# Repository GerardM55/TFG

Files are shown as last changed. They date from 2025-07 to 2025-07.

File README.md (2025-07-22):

# TFG
Este repositorio contiene todos los archivos relacionados con el proyecto de Trabajo de Fin de Grado titulado "Diseño y fabricación de un prototipo de prótesis de mano mioeléctrica con control de voz integrado".

La estructura del repositorio está organizada en las siguientes carpetas:

* Diseño mano

* PCB

* Pruebas

* Scripts finales

* Voz

Cada carpeta incluye los archivos correspondientes, así como un archivo README que explica el funcionamiento de los scripts y detalla los pasos necesarios para su instalación y ejecución.

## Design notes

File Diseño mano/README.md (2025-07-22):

La carpeta Diseño mano contiene los archivos necesarios para la impresión 3D del prototipo de prótesis de mano.
## Archivos SLDPRT 
Dentro de la subcarpeta Archivos SLDPRT se encuentran los archivos CAD en formato .SLDPRT, disponibles para su descarga y modificación.
Esta subcarpeta incluye tanto los archivos utilizados para la impresión del modelo final como versiones alternativas del diseño.
Los archivos .SLDPRT incluidos son los siguientes:
ajustadorSG90
* falange distal 1
* falange distal 2
* falange distal 3
* falange distal 4
* falange distal 5
* falange media 2
* falange media 3
* falange media 4
* falange media 5
* falange proximal 1
* falange proximal 2
* falange proximal 3
* falange proximal 4
* falange proximal 5
* Forearm
* LeftWristCableGuide
* mano
* ServoHolder
* ServoHornPulley
* MCF
* pasador
* soporteSG90
* falange proximal 2 sp
* falange proximal 3 sp
* falange proximal 4 sp
* falange proximal 5 sp 
* caja
* tapa
* ArmStand

## Archivos STL
La carpeta Archivos STL contiene los archivos en formato .STL, preparados y listos para la impresión 3D de las piezas del prototipo.
Los archivos .STL incluidos son los siguientes:
* ajustadorSG90
* falange distal 1
* falange distal 2
* falange distal 3
* falange distal 4
* falange distal 5
* falange media 2
* falange media 3
* falange media 4
* falange media 5
* falange proximal 1
* falange proximal 2
* falange proximal 3
* falange proximal 4
* falange proximal 5
* Forearm
* LeftWristCableGuide
* mano
* ServoHolder
* ServoHornPulley
* MCF
* pasador
* soporteSG90
* falange proximal 2 sp
* falange proximal 3 sp
* falange proximal 4 sp
* falange proximal 5 sp
* caja
* tapa
* ArmStand

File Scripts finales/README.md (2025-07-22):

# Descripción del directorio
En este directorio se encuentran todos los scripts necesarios para la ejecución del sistema. A continuación, 
se explican detalladamente. 

## apagado_script.sh 
El script **apagado_script.sh** es un script de shell que su función es registrar en un archivo de log con 
el inicio y final de su ejecución, junto con la ejecución del script **apagar_ads1292.py**. 
El archivo es ejecutado cuando el pulsador de la PiJuice Zero es presionado dos veces seguidas. 

## apagar_ads1292.py
El script tiene la función de apagar el sistema operativo, concretamente la alimentación a la Raspberry Pi Zero 2W
a través de la PiJuice. 

### Descripción

El script realiza las siguientes acciones:

* Inicializa la comunicación con el dispositivo PiJuice vía I2C.

* Registra en un archivo de log el inicio del proceso de apagado.

*Espera 2 segundos para asegurar el cierre limpio de conexiones.

* Envía la orden de corte de energía para que el PiJuice apague el sistema en 15 segundos.

* Registra en el log la confirmación de la orden enviada o cualquier error ocurrido.

### Requisitos
Las librerías de Python necesarias para la ejecución del script son: 
````
pip install pijuice
````
### Salida 
El script genera un archivo de log en _/home/raspberry/logs/apagar_ads1292.log_ donde se registran los eventos y posibles errores del proceso de apagado.

## inicio_script.sh
Este script de shell es el encargado de la inicialización del sistema. Esta tiene lugar al presionar una vez el pulsador de la Pijuice Zero. 

### Descripción
El archivo realiza las siguientes tareas: 

* Crea los directorios necesarios para logs y notificaciones.

* Finaliza cualquier proceso lgd previo y lanza uno nuevo con la ruta de notificación personalizada.

* Exporta la variable de entorno LGPIO_DIR para asegurar el funcionamiento correcto de lgpio.

* Activa el entorno virtual de Python.

* Carga el overlay de sonido para Google Voice HAT.

* Recarga ALSA para detectar dispositivos de audio.

* Ejecuta el script **script_principal.py** y lo redirige a un archivo de log.

### Requisitos
No se necesita ninguna librería en particular para ejecutar el archivo. 

### Salida 
Se generan dos archivos de log en /home/raspberry/logs:

* **servicio_arranque.log**: Registra los eventos generales del arranque del sistema y la ejecución del script.

* **script_principal.out**: Captura la salida del script Python principal **script_principal.py**, incluyendo posibles errores de ejecución.

## script_principal.py
Es el script encargado de controlar la ejecución principal del sistema y de llamar a los distintos scripts en función de las acciones a realizar. 

### Descripción
El script realiza las siguientes acciones:
* Inicialización de GPIO y recursos compartidos
* Lectura del modo actual
* Modo EMG:
    * Se activa la interfaz SPI del módulo ADS1292 para comenzar la adquisición de señales EMG.
    * Se capta la contracción muscular
    * Si la mano está abierta, se ejecuta el agarre "general".
    * Si la mano está cerrada, se ejecuta "stop".
* Modo voz:
    * Se llama a la función principal del módulo grabar_audio que graba el audio y devuelve una etiqueta con el agarre deseado
    * Si el agarre previo era "stop", se ejecuta el agarre deseado.
    * Si el agarre previo era diferente a "stop", se ejecuta el agarre "stop".
    * El sistema espera 3 segundos por si el usuario quiero cambiar de modo.

### Requisitos
Las librerías necesarias para la ejecución del script son:
````
pip install lgpio
pip install flask
pip install pydub
pip install joblib
pip install vosk
````
### Salida
El script muestra a través de prints el estado de la ejecución. 

## grabar_audio.py
Este script es el encargado de la grabación y transcripción del audio. A continuación, se detalla su funcionamiento. 

### Descripción
El script realiza las siguientes acciones:
* Configuración de GPIO e interrupciones
* Grabación del audio a través de I2S con ALSA.
* El audio se guarda en un archivo wav
* Conversión y transcripción del audio con el transcriptor Vosk
* Limpieza y clasificación del agarre.
* Se devuelve la etiqueta del agarre al script principal.
* Se cierra el I2S y se liberan las GPIOs correspondientes.

### Requisitos
Las librerías necesarias para la ejecución del script son:
````
pip install lgpio
pip install alsaaudio
pip install pydub
pip install joblib
pip install vosk
pip install scikit-learn
pip install unicodedata
````
### Salida
La salida de este script es la devolución del resultado de la transcripción del audio a través de la variable **etiqueta** en la función **main()**. 

## PCA9685.py 
Este script es el encargado de establecer conexión con el módulo PCA9685 y gestionar el movimiento de los servomotores en función del agarre seleccionado. 

### Descripción
El script realiza las siguientes acciones:
* Configura el bus I2C
* Según el tipo de agarre solicitado, determina qué dedos mover, en qué dirección y con qué tipo de movimiento:
  * **R**: Movimiento sin realimentación.
  * **S**: Movimento con realimentación.
* Configura el MUX para gestionar la realimentación en caso de que el agarre no sea ni "stop" ni "general".
* Mueve cada servo al valor definido en el agarre.
* Finaliza liberando recursos (I2C, GPIOs).

### Requisitos
Las librerías necesarias para la ejecución del script son:
````
pip install adafruit-circuitpython-pca9685 lgpio
````

### Salida
El script muestra su estado a través de prints. La salida es visual con los movimientos de los servomotores. 

## ADS1292.py
Este script es el encargado de controlar el ADS1292, el cual tiene dos funciones principales:
* Lectura de la señal EMG.
* Lectura de la realimentación de los servomotores.

### Descripción 
A continuación, se detalla el proceso de ejecución en función del modo utilizado
* Inicializa el bus SPI
* Configura los registros del ADS1292 en función del modo.
* Modo EMG:
    * Espera 6 segundos.
    * Realiza la adquisición de picos para establecer unos margenes para la calibración de picos.
    * Realiza la calibración de picos para establecer un threshold para la detección de la contracción muscular.
    * Adquiere muestras hasta detectar una contracción muscular.
* Modo voz:
    * Calcula el valor de la corriente del servomotor.
    * Devuelve si el servomotor ha superado el límite de corriente.
* Finaliza el bus SPI y libera las GPIOS correspondientes 

### Requisitos
Las librerías necesarias para la ejecución del script son:
````
pip install lgpio numpy scipy
````
### Salida
El script muestra a través de prints los valores adquiridos con el ADS1292.

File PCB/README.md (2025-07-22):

Este directorio contiene dos archivos comprimidos en formato .zip, correspondientes a las placas PCB diseñadas para el proyecto.
Cada archivo .zip incluye dos archivos en formato .json:
PCB.json: Diseño de la placa de circuito impreso (PCB).
schematic.json: Esquema eléctrico con todos los componentes utilizados.

## PCB_1.zip
Contiene el primer modelo de PCB desarrollado durante el proyecto. Este diseño resultó no ser funcional y fue descartado en etapas posteriores.

## PCB_definitiva.zip
Contiene el diseño final de la PCB, utilizado en el modelo funcional del prototipo.

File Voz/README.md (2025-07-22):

Este directorio contiene todos los scripts relacionados con el procesamiento y clasificación de comandos de voz. 
Los archivos están organizados en tres subcarpetas, en función del tipo de preprocesamiento aplicado.
## Algoritmo clasificador
Esta carpeta incluye todos los algoritmos clasificadores entrenados para ser el algoritmo clasificador final. 
Se incluyen 3 subcarpetas divididas en función del algoritmo de preprocesamiento utilizado. Estas 3 carpetas son: 
### MFCC
Este directorio contiene los algoritmos clasificadores entrenados con el preprocesamiento mediane MFCC (Mel-Frequency Cepstral Coefficients ). 
Los algoritmos clasificadores utilizados son el **MLPClassifier, el Random Forest y el SVM**. 
La estructura y funcionamiento de los 3 códigos implementados es la siguiente:
##### Descripción
El programa realiza las siguientes tareas:

* Carga y procesamiento de audios en formato .wav, aplicando:

* Reducción de ruido

* Normalización

* Extracción de características MFCC + deltas

* Clasificación de comandos mediante el algoritmo clasificador seleccionado optimizado con GridSearchCV.

* Evaluación del modelo usando métricas de precisión y matriz de confusión.

* Exportación del modelo entrenado en formato .pkl.

##### Estructura de carpetas esperada
Los audios deben estar organizados por carpetas, una por tipo de agarre o comando. Ejemplo:
```
audio_agarre_normalizados/
├── agarre_cilindrico/
├── agarre_gancho/
├── agarre_obliquo/
├── agarre_pinza/
├── agarre_pinza_lateral/
├── otro/
└── stop/

```
##### Requisitos
Instala las dependencias necesarias con:

```
pip install -r requirements.txt
```
(El archivo requirements.txt debe incluir: librosa, noisereduce, pydub, scikit-learn, matplotlib, joblib, psutil, etc.)

#### Salida
* Precisión del modelo y visualización de la matriz de confusión

* Mejores hiperparámetros encontrados

### Vosk
El directorio siguiente contiene los scripts utilizados para entrenar los algoritmos clasificadores aplicando el transcriptor Vosk. 
Estos algoritmos son: **Linear Regression, MLPClassifier, Random Forest, SVM y XGBoost**. 
La estructura y funcionamiento de los códigos implementados es la siguiente:
#### Descripción
El sistema sigue los siguientes pasos:
* Carga y preprocesamiento de audios

* Normalización de volumen

* Reducción de ruido de fondo

* Transcripción automática usando el modelo de Vosk en español para convertir voz en texto

* Limpieza del texto transcrito mediante la lliminación de acentos y caracteres especiales

* Vectorización del texto

* Entrenamiento del modelo con el algoritmo clasificador seleccionado. 

* Optimización de hiperparámetros con GridSearchCV

* Evaluación del rendimiento
#### Estructura de las carpetas
Los audios están organizados por etiquetas en las siguientes rutas (modificables en el script):
````
Control_de_veu/
├── audio_agarre_normalizados/
│   ├── agarre_cilindrico/
│   ├── agarre_gancho/
│   ├── agarre_obliquo/
│   ├── agarre_pinza/
│   ├── agarre_pinza_lateral/
│   ├── otro/
│   └── stop/
├── vosk-model-es-0.42/
````
#### Requisitos
Asegúrate de tener instaladas las siguientes librerías de Python:
````
pip install numpy pydub noisereduce vosk scikit-learn matplotlib joblib
````
#### Salida
* Precisión impresa en consola.

* Matriz de confusión mostrada con matplotlib.

### Whisper
En esta carpeta se encuentra un modelo con el algoritmo clasificador **MLPCLassifier** y el transcriptor **Whisper ai**. 
La estructura y funcionamiento del códigos es la siguiente:
#### Descripción
El flujo del sistema es el siguiente:

* Carga y preprocesamiento de audios

* Transcripción con el modelo Whisper small en español.

* Limpieza y clasificación semántica

* Extracción de características semánticas

* Clasificación con el modelo MLPClassifier que se entrena con las transcripciones vectorizadas.

* Evaluación mediante el accuracy y una matriz de confusión.

#### Estructura de las carpetas
La estructura de las carpetas es la siguiente: 
````
Control_de_veu/
└── audio_agarre_normalizados/
    ├── agarre_cilindrico/
    ├── agarre_gancho/
    ├── agarre_obliquo/
    ├── agarre_pinza/
    ├── agarre_pinza_lateral/
    ├── stop/
    └── otro/
````
#### Requisitos
Las líbrerias necesarias son las siguientes: 
````
pip install openai-whisper pydub rapidfuzz sentence-transformers scikit-learn matplotlib joblib
````
#### Salida
* Se calcula la precisión del modelo sobre el conjunto de prueba.

* Se muestra una matriz de confusión con los resultados por palabra.

## Detección de voz
En este directorio se encuentran los scripts **deteccion_hyperparametros.py** y **deteccion_voz.py** encargados de la detección de voz del usuario. 
Estos scripts no han sido aplicados al modelo final. A continuación, se detalla los requisitos y estructura de los códigos. 
### deteccion_hyperparametros
Este script implementa un sistema de detección de voz que distingue entre la voz del usuario y la de otras personas. 
Para ello, utiliza un preprocesamiento con MFCC y una red neuronal X-Vector entrenada con PyTorch.

#### Descripción
El sistema realiza las siguientes acciones:
* Carga y preprocesamiento de datos de audio

* Extracción de características (MFCC) con data augmentation

* Definición de un Dataset personalizado

* Entrenamiento de una red neuronal X-Vector

* Búsqueda de hiperparámetros

* Evaluación del rendimiento

* Verificación de hablante a partir de un archivo .wav

#### Estructura de las carpetas
La estructura de las carpetas es la siguiente: 
````
Control_de_veu/
├── audios_deteccio_veu/
│   ├── meva_veu_aug_2/         # Audios de entrenamiento - mi voz
│   ├── altres_veu_aug_2/       # Audios de entrenamiento - otras voces
│   ├── meva_veu_test/          # Audios de test - mi voz
│   └── altres_veu_test/        # Audios de test - otras voces
````
#### Requisitos
Las líbrerias necesarias para ejecutar este script son: 
````
pip install torch librosa numpy scikit-learn
````
#### Salida
* Precisión del modelo. 

* Mejores hiperparámetros encontrados

### deteccion_voz
Este script es una replica del script anterior pero utilizando los mejores hiperparámetros extraidos del código anterior. 
Por lo tanto, la estructura y los requisitos del código son los mismos que el anterior script. 

## Preprocesamiento
En este directorio se encuentran los scripts utilizados para el preprocesamiento de los audios. 
Estos basicamente se dividen en los scripts de data augmentation de la detección de voz, donde se encuentran 
el script **DA_deteccion_mi_voz.py** y **DA_deteccion_otra_voz.py**. Como el nombre del archivo indica,
uno es para el DA de los audios de la voz del usuario y el otro para el DA de los audios externos. 
Posteriormente, hay el script **data_augmentation_audios.py** encargado del DA de los audios de los agarres 
y finalmente, el script **normalizacion_audio.py**, que es el script referente a la normalización de los audios a 16 KHz. 

### DA_deteccion_mi_voz.py, DA_deteccion_otra_voz.py y data_augmentation_audios.py
Estos tres scripts son los encargados del DA. La diferencia entre ellos radica en las carpetas asociadas.

#### Descripción
Los scripts realizan el siguiente: 
* Cargar audios `.wav` desde la carpeta de origen
* Aplicar **data augmentation**
* Guardar tanto el audio original como las versiones aumentadas en la carpeta de destino
  
#### Técnicas aplicadas
* **PitchShift**: Cambia el tono del audio
* **TimeStretch**: Acelera o ralentiza ligeramente el audio
* **AddGaussianNoise**: Añade ruido gaussiano al audio
* **Gain**: Ajusta el volumen general

#### Estructura de las carpetas
La estructua de las carpetas para el script **DA_deteccion_mi_voz.py** es la siguiente: 
````
Control_de_veu/
│
├── audios_deteccio_veu/
│   ├── meva_veu_aug/
│   ├── meva_veu_aug_2/
````
Para el script **DA_deteccion_otra_voz.py**: 
````
Control_de_veu/
│
├── audios_deteccio_veu/
│   ├── altres_veu_aug/
│   ├── altres_veu_aug_2/
````
Y para el script **data_augmentation_audios.py**: 
````
Control_de_veu/
│
└── audio_agarre/
    ├── agarre_X/
    └── agarre_X_aug/
````
#### Requisitos
Las líbrerias necesarias son: 
````
pip install librosa audiomentations numpy soundfile
````
#### Salida
La salida de los scripts es el audio original junto con los audios generados aplicando DA. 

### normalizacion_audio.py
Este script normaliza los audios de entrada a una frecuencia de 16 KHz.
#### Descripción
* Recorre de forma recursiva una carpeta de entrada con archivos .wav

* Convierte los audios que no estén a 16 kHz

* Guarda los audios normalizados en una carpeta de salida

#### Estructura de las carpetas
La estructura de las carpetas es la siguiente. 
````
Control_de_veu/
│
└── audio_agarre/
    ├── agarre_X/
    └── agarre_X_aug/
````
#### Requisitos
Las líbrerias necesarias son: 
````
pip install librosa soundfile
````
#### Salida
La salida del script son los audios normalizados a 16 KHz.

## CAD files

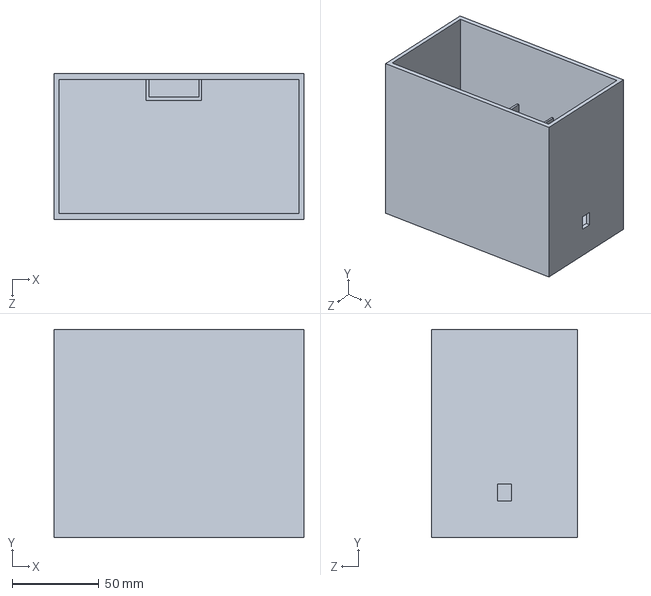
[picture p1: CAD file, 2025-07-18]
Diseño mano/Archivos SLDPRT/caja.SLDPRT
144.0 x 120.0 x 84.0 mm

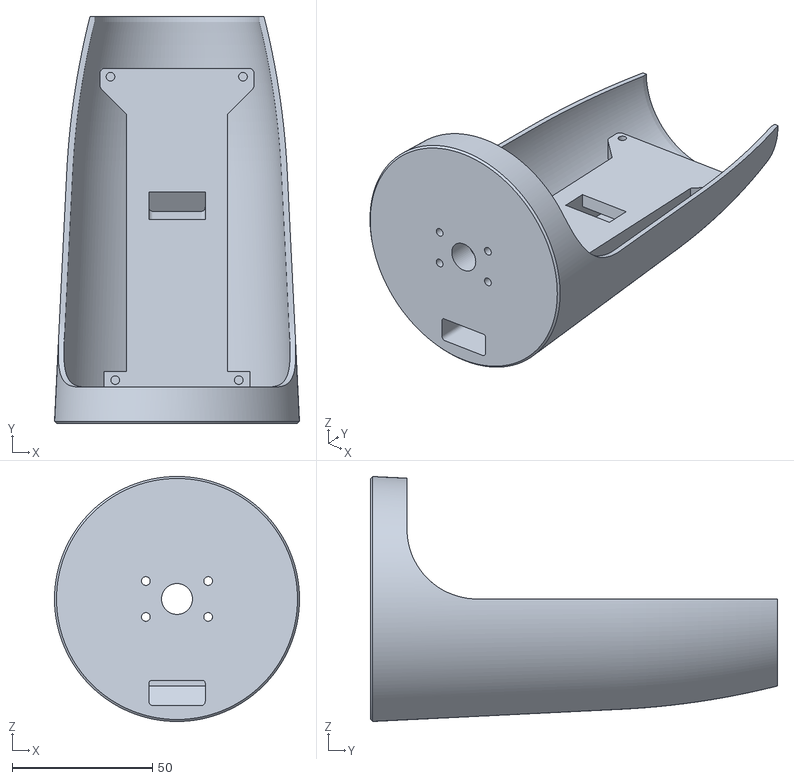
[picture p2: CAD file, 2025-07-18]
Diseño mano/Archivos STL/Forearm.stl
87.3 x 145.0 x 87.3

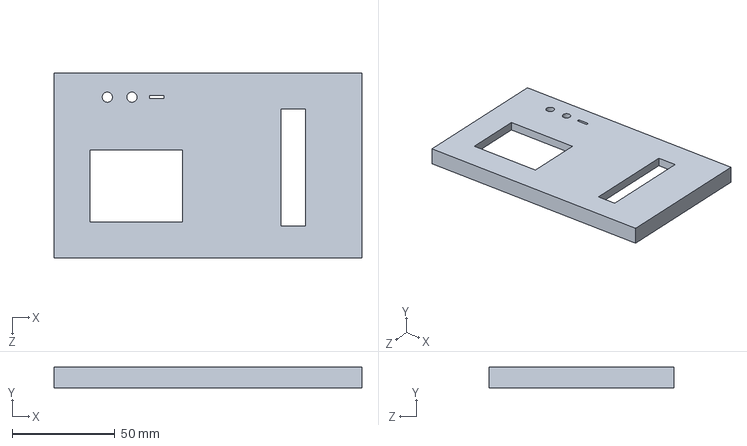
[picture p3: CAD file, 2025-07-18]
Diseño mano/Archivos SLDPRT/tapa.SLDPRT
150.0 x 10.0 x 90.0 mm

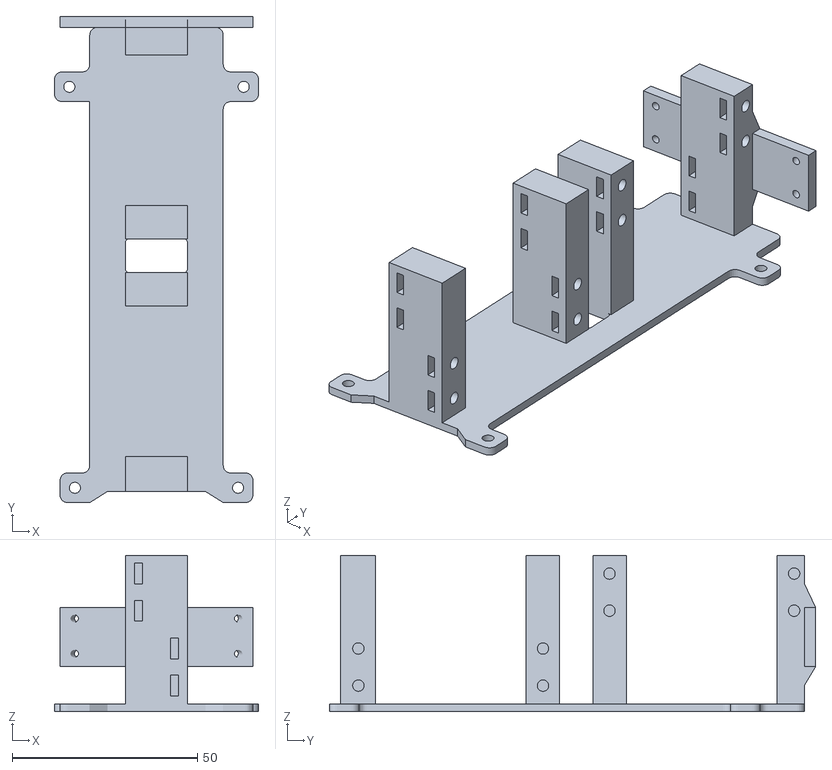
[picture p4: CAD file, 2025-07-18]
Diseño mano/Archivos STL/ServoHolder.stl
55.0 x 131.1 x 42.1

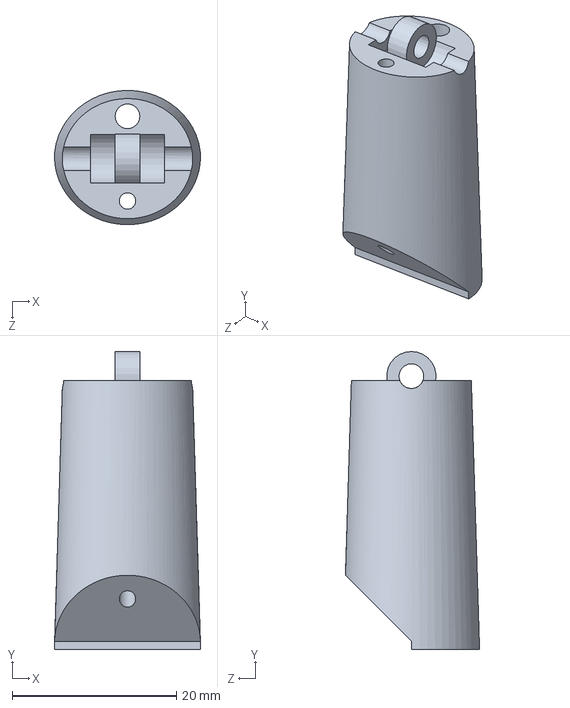
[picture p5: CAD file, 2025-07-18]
Diseño mano/Archivos SLDPRT/falange proximal 5 sp.SLDPRT
17.8 x 36.2 x 16.3 mm

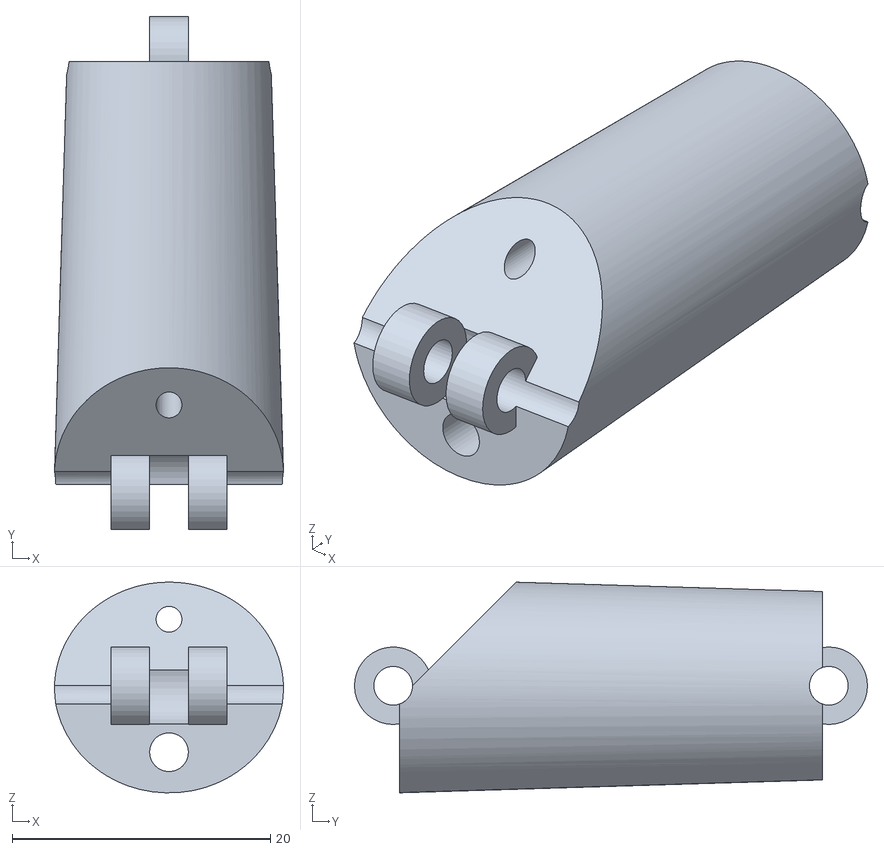
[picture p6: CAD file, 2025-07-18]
Diseño mano/Archivos STL/proximal 5.STL
17.7 x 39.7 x 16.3

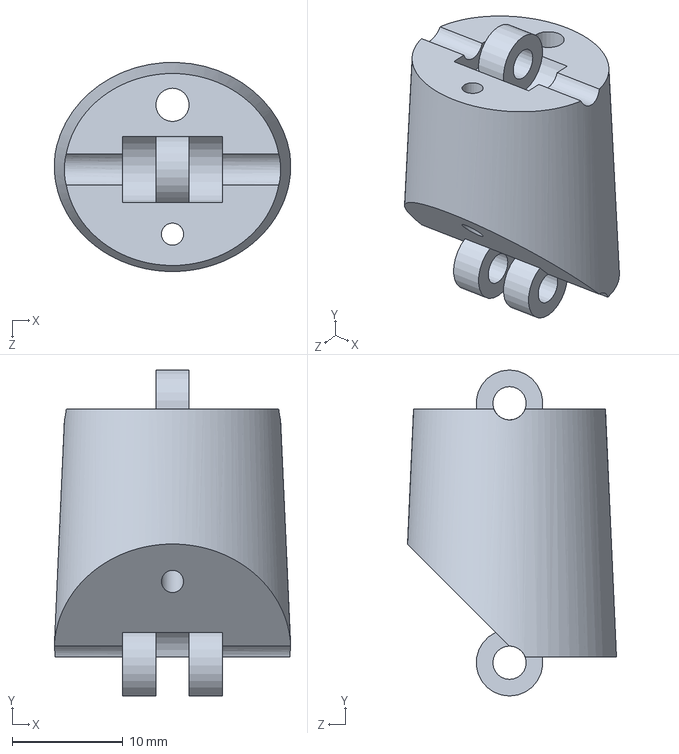
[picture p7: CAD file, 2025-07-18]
Diseño mano/Archivos SLDPRT/falange media 2.SLDPRT
21.3 x 29.4 x 18.8 mm

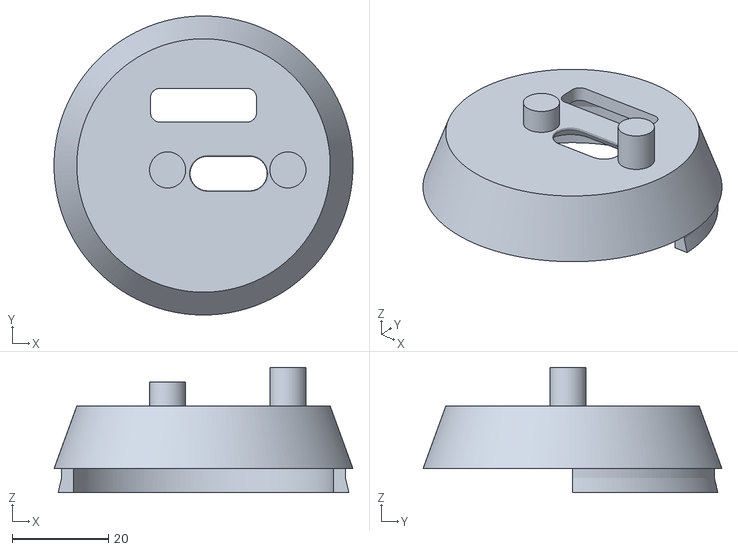
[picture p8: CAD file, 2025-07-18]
Diseño mano/Archivos STL/LeftWristCableGuide.stl
62.0 x 62.0 x 26.0

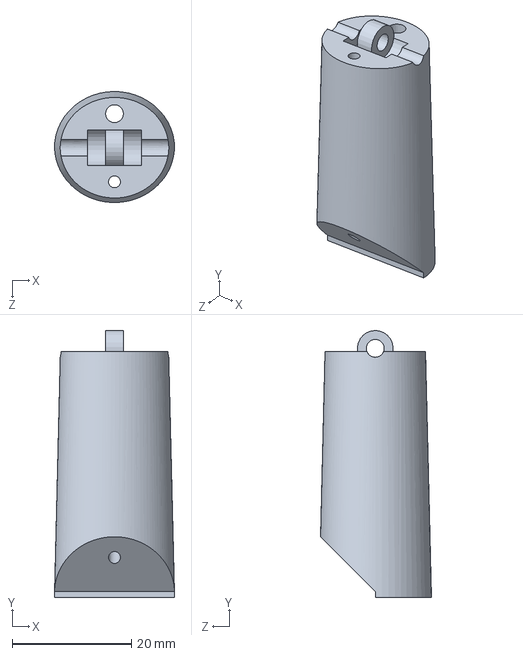
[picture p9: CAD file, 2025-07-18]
Diseño mano/Archivos SLDPRT/falange proximal 4 sp.SLDPRT
20.2 x 44.9 x 18.7 mm

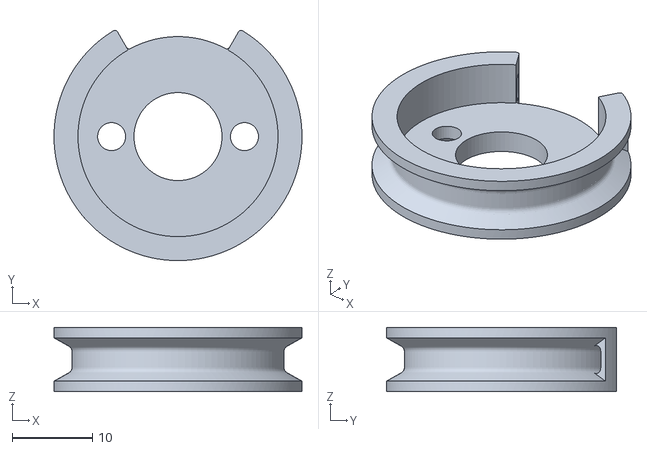
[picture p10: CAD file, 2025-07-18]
Diseño mano/Archivos STL/ServoHornPulley.stl
31.0 x 28.8 x 8.00

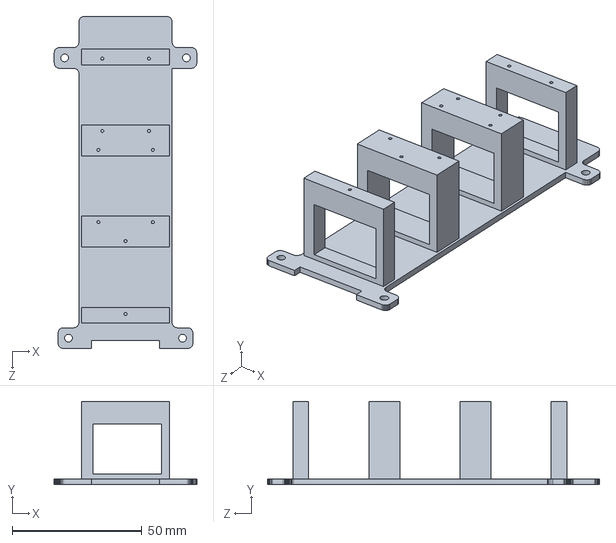
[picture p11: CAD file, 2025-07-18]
Diseño mano/Archivos SLDPRT/soporteSG90.SLDPRT
55.0 x 32.1 x 128.1 mm

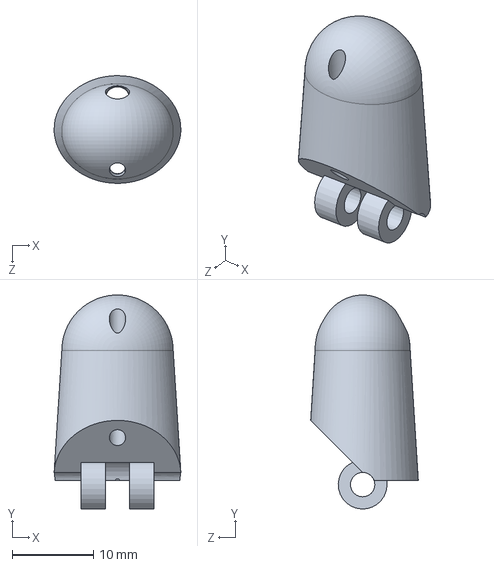
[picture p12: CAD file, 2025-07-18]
Diseño mano/Archivos SLDPRT/falange distal 5.SLDPRT
15.6 x 26.3 x 13.2 mm

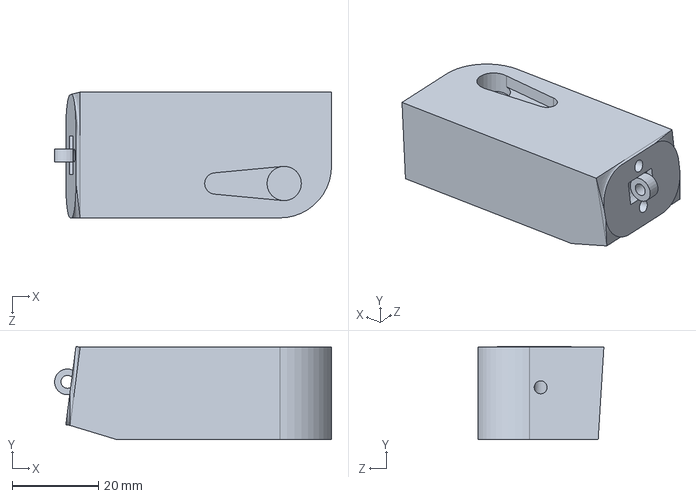
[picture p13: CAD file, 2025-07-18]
Diseño mano/Archivos SLDPRT/MCF.SLDPRT
64.4 x 21.6 x 29.3 mm

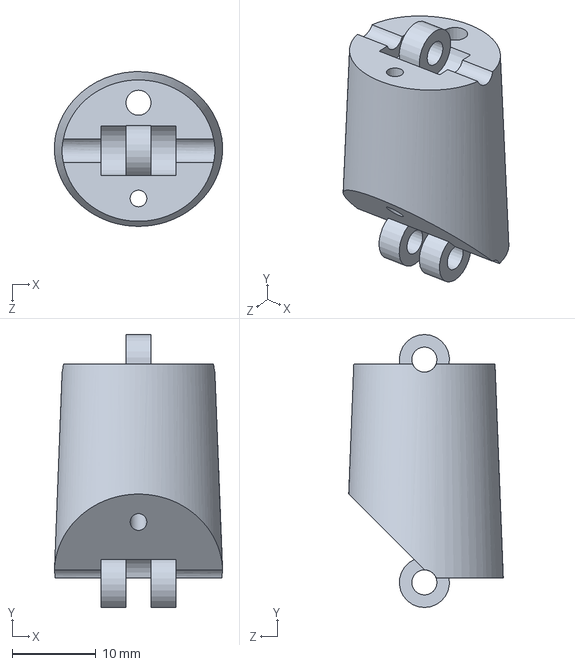
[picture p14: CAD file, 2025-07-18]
Diseño mano/Archivos SLDPRT/falange media 4.SLDPRT
20.1 x 32.6 x 18.5 mm

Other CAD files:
Diseño mano/Archivos SLDPRT/falange proximal 4.SLDPRT
Diseño mano/Archivos SLDPRT/falange proximal 3.SLDPRT
Diseño mano/Archivos SLDPRT/falange proximal 2.SLDPRT
Diseño mano/Archivos SLDPRT/pasador.SLDPRT
Diseño mano/Archivos SLDPRT/ajustadorSG90.SLDPRT
Diseño mano/Archivos SLDPRT/falange distal 1.SLDPRT
Diseño mano/Archivos SLDPRT/falange distal 2.SLDPRT
Diseño mano/Archivos SLDPRT/falange distal 3.SLDPRT
Diseño mano/Archivos SLDPRT/falange distal 4.SLDPRT
Diseño mano/Archivos SLDPRT/falange media 3.SLDPRT
Diseño mano/Archivos SLDPRT/falange media 5.SLDPRT
Diseño mano/Archivos SLDPRT/falange proximal 1.SLDPRT
Diseño mano/Archivos SLDPRT/falange proximal 2 sp.SLDPRT
Diseño mano/Archivos SLDPRT/falange proximal 3 sp.SLDPRT
Diseño mano/Archivos SLDPRT/falange proximal 5.SLDPRT
Diseño mano/Archivos SLDPRT/mano.SLDPRT
Diseño mano/Archivos SLDPRT/servoHorn.SLDPRT
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

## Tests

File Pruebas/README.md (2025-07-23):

# Descripción del directorio
En este directorio estan disponibles todos los archivos utilizados para las pruebas del proyecto. 
A continuación, se describe el funcionamiento y los requisitos necesarios para el uso de cada script. 
## calibracion_agarres.py
La función de este script es calibrar los rangos de los servomotores en función del agarre deseado. 

### Descripción
El script realiza las siguientes acciones: 
* Inicializa el bus I2C y el módulo PCA9685.

* Define los canales y movimientos correspondientes a cada dedo.
* Ejecuta el agarre "stop".
* Ejecuta el agarre deseado.
* Regresa a la posición de reposo mediante la ejecución del aggare "stop".

### Requisitos
Las líbrerias necesarias son las siguientes: 
````
pip install adafruit-circuitpython-pca9685 adafruit-blinka
````
### Salida
La salida del script es la ejecución del agarre. El usuario debe modificar manualmente la variable 
**agarre** con un agarre dentro del diccionario **agarre_config**. 
También debe modificar los valores numéricos de caga agarre del diccionario **agarre_config** en función del resultado
del agarre que observe y del rango de movimiento permitido por cada servomotor. 

## calibracion_agarres.py
Este script es el encargado de calibrar el rango de movimientos de cada servomotor por individual. 

### Descripción
El script realiza lo siguiente: 
* Inicializa el bus I2C.
* Configura la frecuencia a 50 Hz.
* Mueve el servo a dos posiciones estándar:
  *  -90° (izquierda): pulso de X ms
  *  +90° (derecha): pulso de X ms
* Espera que el usuario presione Enter antes de mover a cada posición.

### Requisitos 
Las líbrerias necesarias son las siguientes: 
````
pip install adafruit-circuitpython-pca9685 adafruit-blinka
````
### Salida
La salida del script es el movimiento de cada servomotor. Para ajustar este movimiento, el usuario debe modificar
manualmente los valores de la variable **posiciones**. 

## comunicacionserieads.zip
El archivo zip contiene el proyecto de PlatformIO utilizado para obtener la señal EMG y hacer las pruebas con el ESP32

### Descripción 
El archivo **main.cpp** realiza las siguientes funciones: 
* Inicia la comunicación SPI del ADS1292 con el ESP32.
* Configura los registros del ADS1292
* Espera 6 segundos antes de iniciar la calibración de picos
* Adquiere 200 picos y calcula la mediana y la MAD. 
* Aplica unos rangos de detección de picos en función de los valores anteriores
* Adquiere 30 picos y calcula un threshold en función de la media y la desviación estándar
* Adquiere la señal y calcula si los picos son superiores al threshold para determinar si hay contracción muscular

### Requisitos
Las dependencias utilizadas son las siguientes: 
````
#include <Arduino.h>
#include <SPI.h>
#include <stdint.h>
#include <stdbool.h>
#include <time.h>
#include <stdio.h>
#include <Filters.h>
#include <AH/Timing/MillisMicrosTimer.hpp>
#include <Filters/Notch.hpp>
#include <vector>
#include <Filters/MedianFilter.hpp> 
#include <Filters/Butterworth.hpp>
#include <AH/Timing/MillisMicrosTimer.hpp>
````
### Salida
La salida del archivo es la indicación de la terminal del momento en que ha detectado que un pico es superior al threshold. 
El usuario debe ajustar manualmente los siguientes valores:
* El número que múltiplica la variable **mad** en las variables **PEAK_MIN_HEIGHT** y **PEAK_MAX_HEIGHT**. 
* El número que múltplica la variable **peakStdDev** para obtener la variable **threshold**.
* Descomentar la línea 430 y 431 y comentar desde la linea 432 a la 541 en función de si quiere
* ver la señal por puerto serie o ejecutar el algoritmo de detección de la contracción.

## movimiento_sg90.py
Este script es el encargado de la calibración del servomotor SG90 que realiza el movimiento de abducción 
y aducción del dedo pulgar. 
### Descripción
El script realiza las siguientes acciones:  
* Inicializa el bus I2C y el módulo PCA9685.  
* Define el canal PWM que controla el servo.  
* Ejecuta un movimiento suave del servo desde la posición inicial a la final y regresa.  
* Libera los recursos del PCA9685.

### Requisitos
Las librerías necesarias son las siguientes:
````
pip install adafruit-circuitpython-pca9685 adafruit-blinka
````
### Salida
El output del script es el movimiento de aducción/abducción del servomotor SG90. El usuario debe 
editar manualmente los dos primeros parámetros de la función **mover_suavemente()** en función de los rangos de movimiento. 

## prueba_ads1292.py
Este script es el encargado de verificar la correcta comunicación SPI entre el ADS1292 y la Raspberry Pi Zero 2W. 

### Descripción
El script realiza las siguientes acciones:  
* Inicializa los pines GPIO necesarios para la comunicación con el ADS1292.  
* Inicializa la interfaz SPI para establecer comunicación con el chip.  
* Envía comandos de reinicio y configuración al ADS1292.  
* Lee el registro de ID del chip y verifica si la conexión es correcta.  
* Si no se detecta el ID válido (`0x53`), reintenta hasta 3 veces.  
* Finaliza cerrando SPI y liberando los recursos GPIO

### Requisitos
Las librerías necesarias son las siguientes: 
````
pip install lgpio spidev
````
### Salida
La salida del script es la verificación por consola de la correcta comunicación por SPI. Si se establece comunicación
se muestra por pantalla: ✅ ID válido detectado. Contrariamente, se muestra: ⚠️ Error: No se ha detectado ID válido después de 3 intentos.

## prueba_audio_sinpulsador.py y prueba_vosk+ics43434.py
Estos dos scripts se ejecutan conjuntamente para realizar la misma prueba. Esta consiste en verificar el tiempo de ejecución de ambos scripts. 

### Descripción

El conjunto de scripts realiza las siguientes acciones:

* Inicializa el micrófono conectado por I2S para capturar audio cuando se detecta una señal en el pin GPIO 26.
* Graba audio en formato WAV mientras se mantiene la señal activa.
* Una vez terminada la grabación, guarda el archivo en disco y ejecuta un segundo script de análisis.
* El segundo script convierte el audio a un formato compatible con Vosk y realiza transcripción automática del contenido hablado.
* La transcripción es clasificada.
* El resultado final muestra por consola la **transcripción** y la **etiqueta de clasificación** correspondiente.
* Finalmente, el archivo de audio temporal se elimina del sistema.

### Requisitos

Las librerías necesarias para ambos scripts son las siguientes:
````
pip install lgpio spidev pydub vosk joblib
````
### Salida
La salida del script es la transcripción del audio grabado junto con la duración del proceso. 
Esta segunda salida es el resultado que se busca al realizar esta prueba. 

## transcriptor_audio.py
Este script realiza la misma función que los scripts anteriores, la diferencia es que este realiza la transcripción
sin realizar un **subprocess**. 

### Descripción
El script realiza las siguientes acciones:
Captura de audio controlada por eventos GPIO (pin 26).

* Inicializa el micrófono conectado por I2S para capturar audio cuando se detecta una señal en el pin GPIO 26.

* Graba el audio en formato WAV mientras la señal se mantiene activa.

* Guarda el archivo de audio.

* Añade el archivo a una cola para procesarlo en segundo plano.

* Convierte el audio a un formato compatible con Vosk (mono, 16 kHz, 16 bits).

* Realiza transcripción automática del contenido con el transcriptor Vosk.

* Clasifica la transcripción.

* Muestra en consola la etiqueta resultante de la clasificación.

### Requisitos
Las librerías necesarias para ejecutar el script son:
````
pip install alsaaudio lgpio joblib vosk pydub
````
### Salida
El resultado del script es la impresión por consola de la transcripción junto con la duración del proceso. 

## prueba_conceptos_previos.ino
En este script hay el código utilizado durante las pruebas de conceptos previos. Para su ejecución se necesita una **Arduino Shield** y 
el dispositivo **MySignals hw2 libelium**. 

### Descripción
El script realiza las siguientes acciones:

* Captura la señal EMG mediante la placa MySignals.

* Aplica un filtro pasa banda (10-500 Hz).

* Almacena los datos filtrados en un buffer circular para calcular continuamente el umbral de ruido.

* Calcula el umbral de ruido como la media más dos desviaciones estándar de la señal reciente.

* Detecta la activación y desactivación muscular comparando la señal filtrada con el umbral de ruido, considerando un tiempo mínimo de estabilidad (20 ms) para evitar falsos positivos.

* Reporta por serial el estado del músculo: "Músculo ON" o "Músculo OFF".

### Requisitos
Las dependencias utilizadas son las siguientes: 
````
#include <MySignals.h>
#include "Wire.h"
#include "SPI.h"
````
### Salida
A través del Serial Plot de Arduino se puede observar la forma de la señal y el estado del músculo. 

## prueba_micropin.py
Este script realiza la prueba para observar el cambio de estado de la GPIO 14 asociada al conmutador SPST del cambio de modo EMG a voz y vicerversa. 

### Descripción 
El script realiza las siguientes acciones:

* Monitorea cambios en el pin GPIO 14, configurado como entrada.

* Cada vez que se detecta un cambio de nivel (flanco ascendente o descendente) en ese pin, alterna el modo entre "emg" y "voz".

* Imprime en consola el modo actual tras cada cambio.

### Requisitos 
Las librerías necesarias para ejecutar el script son:
````
pip install lgpio spidev
````
### Salida
El script muestra por consola el estado de la GPIO y cada vez que hay un cambio de estado. 

## prueba_retroalimentacion.py
Este script es usado para verificar los valores devueltos por el ADS1292 referentes a la retroalimentación de los servomotores. 
La función principal del script es realizar el movimiento de flexión de un dedo y obtener los valores
de intensidad del ADS1292 mediante el script **prueba_EMG_ads1292.py**. 

### Descripción 
El script realiza las siguientes acciones:

* Inicializar el bus I2C y el controlador PCA9685.

* Configurar el MUX para seleccionar la señal de control del dedo deseado.

* Mover el servos suavemente por pasos en función del dedo deseado.

* Leer la señal de realimentación del ADS1292.

### Requisitos 
Las librerías necesarias para ejecutar el script son:
````
pip install adafruit-circuitpython-pca9685 lgpio adafruit-blinka
````
### Salida
La salida del script es la impresión por pantalla de los valores devueltos por el ADS1292, junto con el movimiento
del dedo deseado. 

## prueba_EMG_ads1292.py
Este script verifica tanto la correcta adquisición de la señal EMG a través del ADS1292 como el correcto funcionamiento de la detección de contracciones musculares. 
El código es el mismo que el del script **ADS1292.py** añadiendo una función **main()** que gestiona el proceso (en lugar de ser gestionado a través del script_principal.py). Por lo tanto, la descripción exhaustiva del script se puede leer en el README.md del archivo Scripts_finales. La importancia del script es que el usuario debe ajustar los siguientes parámetros para que la detección de la contracción muscular sea más eficiente: 
* El número que múltiplica la variable **mad** en las variables **PEAK_MIN_HEIGHT** y **PEAK_MAX_HEIGHT**. 
* El número que múltplica la variable **peakStdDev** para obtener la variable **threshold**.
* El tiempo de calibración (línea 469).

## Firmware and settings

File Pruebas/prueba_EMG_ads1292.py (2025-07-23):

import spidev
import lgpio
import time
import math
from collections import deque
import numpy as np
import threading
import struct
import os
import select
import scipy.signal
import script_principal

# --- CONSTANTES GLOBAL ---
dataSize = 9   # 3 status + 2 channels * 3 bytes
spiDummyByte = 0x00  # Byte de relleno para SPI
config1Value= 0x02 #Registro de configuración 1 del ADS1292
fc = 245     # Frecuencia de corte (Hz)
fs = 500     # Frecuencia de muestreo (Hz)
order = 4    # Orden del filtro

# --- CONSTANTES EMG ---
vref = 2.42 # Voltaje de referencia del ADS1292
emgPga = 12.0 # Ganancia del amplificador de instrumentación en el modo EMG
sampleSize = 100 # Tamaño del buffer de picos
peakWindow = 5 # Tamaño de la ventana de picos
peakSampleSize = 200  # Tamaño del buffer de picos iniciales
config2EMG=0xA0 # Valor del registro de configuración 2 del ADS1292 en modo EMG      
ch1setEMG=0x60 # Valor del registro CH1SET del ADS1292 en modo EMG       
ch2setEMG=0x81 # Valor del registro CH2SET del ADS1292 en modo EMG
rldsenseEMG=0xE3 # Valor del registro RLD_SENS del ADS1292 en modo EMG      
resp1EMG=0x02 # Valor del registro RESP1 del ADS1292 en modo EMG
resp2EMG=0x07 # Valor del registro RESP2 del ADS1292 en modo EMG

# --- BUFFERS ---
emgBuffer = np.zeros(peakWindow, dtype=np.int32) # Buffer para almacenar los últimos 3 valores EMG
peakValues = np.zeros(sampleSize, dtype=np.int32) # Buffer para almacenar los picos detectados
initialPeaks = np.zeros(peakSampleSize, dtype=np.int32) # Buffer para almacenar los picos iniciales

# --- VARIABLES EMG---
dataReady = False # Variable que indica si hay datos listos para leer
calibrationStarted = False # Variable que indica si se ha iniciado la calibración
calibrationDone = False # Variable que indica si la calibración ha finalizado
detected_peak = False # Para parar la lectura
peakCount = 0 # Contador de picos detectados
peakMedian = np.int32(0) # Mediana de los picos detectados
peakStdDev = np.int32(0) # Desviación estándar de los picos detectados
threshold = np.int32(0) # Umbral para la detección de picos
lastPeakValue = np.int32(0) # Último valor de pico detectado
bufferFillCount = 0 # Contador de llenado del buffer EMG
lowPeakCount = 0 # Contador de picos bajos detectados
emgData = np.int32(0) # Variable para almacenar el valor EMG actual
initialPeakCount = 0 # Contador de picos iniciales detectados
peakRangeComputed = False # Variable que indica si el rango de picos ha sido calculado
peakMinRange = np.int32(0) # Rango mínimo de picos detectados
peakMaxRange = np.int32(0) # Rango máximo de picos detectados

# --- CONSTANTES SERVOMOTOR ---
shuntResistance = ((0.5*0.17)/(0.5+0.17)) # Valor de la resistencia de shunt que es el valor equivalente al paralelo de la resistencia de 0.5 ohmios y 0.17 ohmios
currentThreshold = 1 # Umbral de corriente para la detección de contracción del servomotor
servoPga = 1.0 # Ganancia del amplificador de instrumentación en el modo servomotor
config2Servo=0xB0 # Valor del registro de configuración 2 del ADS1292 para calcular la realimentación del servomotor
ch1setServo=0x81 # Valor del registro CH1SET del ADS1292 para calcular la realimentación del servomotor
ch2setServo=0x10 # Valor del registro CH2SET del ADS1292 para calcular la realimentación del servomotor
rldsenseServo=0xC0 # Valor del registro RLD_SENS del ADS1292 para calcular la realimentación del servomotor
resp1Servo=0x02 # Valor del registro RESP1 del ADS1292 para calcular la realimentación del servomotor
resp2Servo=0x07 # Valor del registro RESP2 del ADS1292 para calcular la realimentación del servomotor

# --- VARIABLES SERVOMOTOR  ---
servoData = np.int32(0) # Variable para almacenar el valor del servomotor actual
# --- COMANDOS ADS1292 ---
CMD_WAKEUP = 0x02 
CMD_STANDBY = 0x04
CMD_RESET = 0x06
CMD_START = 0x08
CMD_STOP = 0x0A
CMD_RDATAC = 0x10
CMD_SDATAC = 0x11
CMD_RDATA = 0x12

# --- PINES ---
ADS1292_DRDY_PIN = 5
ADS1292_START_PIN = 27
ADS1292_PWDN_PIN = 17

# --- VARIABLES GLOBALES ---
data_preparada = False # Variable que indica si los datos están preparados para ser leídos
CONFIG_SPI_MASTER_DUMMY = 0x00 # Byte de relleno para la comunicación SPI
chip=None # Variable para almacenar el chip GPIO
mano_abierta=True # Variable que indica si la mano está abierta
modo="voz" # Variable que indica el modo de operación
modo_change=False # Variable que indica si el modo ha cambiado
spi=None # Variable para almacenar la instancia de comunicación SPI

# --- Registros ---
CONFIG1 = 0x01
CONFIG2 = 0x02
CH1SET = 0x04
CH2SET = 0x05
RLD_SENS = 0x06
RESP1 = 0x09
RESP2 = 0x0A

# --- FUNCIONES ADS1292 ---

def send_command(command):
    # --- Función que envía un comando al ADS1292 ---
    global spi
    time.sleep(2e-6)
    spi.xfer2([command])
    time.sleep(0.001)

def read_register(reg):
    # --- Función que lee un registro del ADS1292 ---
    global spi
    spi.xfer2([0x20 | reg, 0x00])
    time.sleep(1e-3)
    data = spi.xfer2([0x00])
    return data[0]

def write_register(reg, val):
    # --- Función que escribe un valor en un registro del ADS1292 ---
    global spi
    spi.xfer2([0x40 | reg, 0x00, val])
    time.sleep(0.01)

def enable_continuous_reading():
    # --- Función que activa la lectura continua de datos del ADS1292 ---
    send_command(CMD_RDATAC)

def disable_continuous_reading():
    # --- Función que desactiva la lectura continua de datos del ADS1292 ---
    send_command(CMD_SDATAC)

def start_conversion():
    # --- Función que inicia la conversión de datos del ADS1292 ---
    send_command(CMD_START)

def stop_conversion():
    # --- Función que detiene la conversión de datos del ADS1292 ---
    send_command(CMD_STOP)

def read_data():
    # --- Función que lee los datos del ADS1292 ---
    data = spi.xfer2([CMD_RDATA] + [0x00] * 9)
    return data[1:]

def reset_ads1292():
    # --- Función que resetea el ADS1292 ---
    global chip
    lgpio.gpio_write(chip, ADS1292_PWDN_PIN, 0)
    time.sleep(0.002)
    lgpio.gpio_write(chip, ADS1292_PWDN_PIN, 1)
    time.sleep(0.1)
    send_command(CMD_RESET)
    time.sleep(0.01)
    send_command(CMD_SDATAC)
    time.sleep(0.01)
    lgpio.gpio_write(chip, ADS1292_START_PIN, 1)

def config_ini():
    # --- Config GPIO ---
    global chip
    #chip = lgpio.gpiochip_open(0)
    lgpio.gpio_claim_output(chip, ADS1292_START_PIN)
    lgpio.gpio_claim_output(chip, ADS1292_PWDN_PIN)
    lgpio.gpio_claim_input(chip, ADS1292_DRDY_PIN)

def configuracion_ini():
    # --- Config GPIO ---
    global chip
    chip = lgpio.gpiochip_open(0)
    lgpio.gpio_claim_output(chip, ADS1292_START_PIN)
    lgpio.gpio_claim_output(chip, ADS1292_PWDN_PIN)
    lgpio.gpio_claim_input(chip, ADS1292_DRDY_PIN)
    #prueba_retroalimentacion.compartir_chip(chip)
    return chip
 
# --- FUNCIONES GLOBALES ---

def spi_ini():
    # --- Función que configura la comunicación SPI e inicializa el ADS1292 ---
    global spi, chip
    spi = spidev.SpiDev()
    spi.open(0, 0)
    spi.max_speed_hz = 500000
    spi.mode = 0b01
    
    # inicialización del ADS1292
    lgpio.gpio_write(chip, ADS1292_PWDN_PIN, 1)
    time.sleep(0.1)
    lgpio.gpio_write(chip, ADS1292_PWDN_PIN, 0)
    time.sleep(0.1)
    lgpio.gpio_write(chip, ADS1292_PWDN_PIN, 1)
    time.sleep(0.1)
    lgpio.gpio_write(chip, ADS1292_START_PIN, 0)
    time.sleep(0.02)

def comprobar_spi():
    # --- Función que comprueba la correcta comunicación SPI entre el ADS1292 y la Z2W ---
    for i in range(3):
        id_val = read_register(0x00)
        print(f"Intent {i+1}: Registre ID = 0x{id_val:02X}")
        if id_val == 0x53:
            print("✅ ID vàlid detectat.")
            return True
        reset_ads1292()
        time.sleep(0.1)
    print("⚠️ Error: No ID vàlid després de 3 intents.")
    return False

def leer_valores_ADS1292():
    # --- Función de lectura de datos del ADS1292 ---
    global emgData, servoData
    spiBuffer = spi.xfer2([CONFIG_SPI_MASTER_DUMMY] * 9)

    # Lectura del canal EMG
    # Leer como uint32 sin signo
    rawEmg = (np.uint32(spiBuffer[3]) << 16) | (np.uint32(spiBuffer[4]) << 8) | np.uint32(spiBuffer[5])
    if rawEmg & 0x800000:  # Si el bit de signo está activado
        rawEmg |= 0xFF000000  # Extiende el signo a 32 bits
    emgData = np.int32(rawEmg)

    # Lectura del canal de servomotor
    rawServo = (np.uint32(spiBuffer[6]) << 16) | (np.uint32(spiBuffer[7]) << 8) | np.uint32(spiBuffer[8])
    if rawServo & 0x800000:
        rawServo |= 0xFF000000
    servoData = np.int32(rawServo)

def comprobar_registros(state):
    # --- Función de comprueba que la correcta configuración de los registros del ADS1292 ---
    cf2 = read_register(CONFIG2) # Lectura del registro CONFIG2
    ch1 = read_register(CH1SET) # Lectura del registro CH1SET
    ch2 = read_register(CH2SET) # Lectura del registro CH2SET
    rld = read_register(RLD_SENS) # Lectura del registro RLD_SENS
    resp = read_register(RESP2) # Lectura del registro RESP2

    print(f"CH1SET: 0x{ch1:02X}")
    print(f"CH2SET: 0x{ch2:02X}")
    print(f"RLD_SENS: 0x{rld:02X}")
    print(f"RESP2: 0x{resp:02X}")
    print("--------------------")
    if state == "emg": # Si los valores adquiridos del modo EMG no son iguales a los valores esperados, devuelve False
        if cf2 != config2EMG or ch1 != ch1setEMG or ch2 != ch2setEMG or rld != rldsenseEMG or resp != resp2EMG:
            return False
        
    else: # Si los valores adquiridos del modo servomotor no son iguales a los valores esperados, devuelve False
        if cf2 != config2Servo or ch1 != ch1setServo or ch2 != ch2setServo or rld != rldsenseServo or resp != resp2Servo:
            return False
    
    return True

def activar_spi():
    # --- Función para activar la comunicación serie SPI ---
    global chip, spi
    spi_ini()

def desactivar_spi():
    # --- Función para desactivar la comunicación serie SPI ---
    global spi
    spi.close()

# --- FUNCIONES EMG ---   
#  
def emg_configuracion():
    # --- Función que configura los registros del ADS1292 para la lectura del EMG ---
    disable_continuous_reading()
    write_register(CONFIG1, config1Value)
    time.sleep(0.1)
    write_register(CONFIG2, config2EMG)
    time.sleep(0.1)
    write_register(0x03,0x10)
    time.sleep(0.1)
    write_register(CH1SET, ch1setEMG)
    time.sleep(0.1)
    write_register(CH2SET, ch2setEMG)
    time.sleep(0.1)
    write_register(RLD_SENS, rldsenseEMG)
    time.sleep(0.1)
    write_register(RESP1, resp1EMG)
    time.sleep(0.1)
    write_register(RESP2, resp2EMG)
    
def esperar_DRDY(chip, gpio, level, tick):
    # --- Función llamada cuando DRDY cambia a nivel bajo y que pone la variable dataReady a True ---
    global dataReady
    dataReady=True
    
def emg_inicializacion():
    # --- Función encargada de la inicialización y correcta configuración del ADS1292 previa a la adquisición de datos del EMG ---
    global chip
    configuration = False
    while not configuration: # Mientras no se haya configurado correctamente el ADS1292
        reset_ads1292() # Resetea el ADS1292
        emg_configuracion() # Configura el ADS1292
        configuration=comprobar_registros("emg")   # Verifica registros
        time.sleep(0.008)     # delay(8) ms en Arduino
    enable_continuous_reading() # Activa la lectura continua de datos
    time.sleep(0.01)
    start_conversion()
    time.sleep(0.01)
    
def stop_lectura_emg():
    # --- Función encargada de parar la adquisición de datos por parte del ADS1292 y el tratado posterior a las variables y pines involucrados en la adquisición ---
    global detected_peak, calibrationStarted, peakRangeComputed

    print("🛑 Deteniendo lectura EMG...")
    
    # Enviar comando RDATAC para desactivar lectura continua
    disable_continuous_reading()

    # Detener conversiones
    stop_conversion()
    
    #Liberar DRDY pin
    lgpio.gpio_free(chip, ADS1292_DRDY_PIN)
    calibrationStarted=False
    peakRangeComputed=False

    print("✅ EMG detenido completamente.")

def lectura_emg():
    # --- Función principal encargada de la configuración, adquisición y lectura del threshold en el modo emg ---
    global chip, dataReady, detected_peak, peakRangeComputed, calibrationDone 

    # Inicializa EMG (configuración, buffers, etc.)
    emg_inicializacion()
    
    # Reincia los valores de las variables del emg para que se haga la calibracion
    reiniciar_valores_emg()

    # Configura callback DRDY
    lgpio.gpio_claim_alert(chip, ADS1292_DRDY_PIN, lgpio.FALLING_EDGE, lgpio.SET_PULL_UP)
    lgpio.callback(chip, ADS1292_DRDY_PIN, lgpio.FALLING_EDGE, esperar_DRDY)

    # Inicia hilo de polling
    detected_peak = False
    poll_thread = threading.Thread(target=polling_drdy, daemon=True)
    poll_thread.start()

    # Espera hasta que se detecte un pico válido
    while not detected_peak:
        time.sleep(0.01)
    stop_lectura_emg()

def reiniciar_valores_emg():
     # --- Función encargada de reiniciar las variables asociadas al EMG para la próxima adquisición ---
    global peakRangeComputed, calibrationDone, calibrationStarted
    global peakCount, initialPeakCount
    global threshold, peakStdDev, lastPeakValue, lowPeakCount, bufferFillCount
    global peakValues, initialPeaks, emgBuffer
    
    # Reset de banderas de estado
    peakRangeComputed = False
    calibrationDone = False
    calibrationStarted = False

    # Reset de contadores y umbrales
    peakCount = 0
    initialPeakCount = 0
    threshold = 0
    peakStdDev = 0
    lastPeakValue = 0
    lowPeakCount = 0
    bufferFillCount = 0

    # Limpieza de buffers de picos y señal EMG
    peakValues.fill(0)
    initialPeaks.fill(0)
    emgBuffer.fill(0)


# --- FUNCIONES DETECCIÓN DE LA CONTRACCIÓN ---

def millis():
    # --- Función encargada de devolver el tiempo actual en milisegundos---
    return int(round(time.time() * 1000))


def adquirir_picos_iniciales(emg_value):
    # --- Función encargada de adquirir los picos iniciales---
    global initialPeakCount, peakRangeComputed, PEAK_MIN_HEIGHT, PEAK_MAX_HEIGHT

    if es_pico() and initialPeakCount < peakSampleSize : # Si es un pico y no se ha alcanzado el tamaño del buffer de picos iniciales se añade al buffer
        initialPeaks[initialPeakCount] = emgBuffer[1]
        initialPeakCount += 1

    if initialPeakCount >= peakSampleSize:
        sorted_peaks = np.sort(initialPeaks)
        # Median
        median = np.median(sorted_peaks)

        # Median Absolute Deviation (MAD)
        abs_diffs = np.abs(initialPeaks - median)
        mad = np.median(abs_diffs)

        print(f"📉 Median Absolute Deviation (MAD): {mad}")
        print(f"📊 Median: {median}")

        PEAK_MIN_HEIGHT = int(median - 5 * mad) # Ajuste del rango mínimo de picos
        PEAK_MAX_HEIGHT = int(median + 5 * mad) # Ajuste del rango máximo de picos

        peakRangeComputed = True

        print("✅ Peak range adjusted with tertiles:")
        print(f"PEAK_MIN_HEIGHT = {PEAK_MIN_HEIGHT}")
        print(f"PEAK_MAX_HEIGHT = {PEAK_MAX_HEIGHT}")


def calibrar_threshold():
    # --- Función encargada de calcular la mediana y la desviación standard para determinar un threshold---
    global emgBuffer, calibrationDone, threshold, peakStdDev, peakCount, lastPeakValue, lowPeakCount

    if es_pico_de_calibracion(emgBuffer[1]) and peakCount < sampleSize: # Si es un pico de calibración y no se ha alcanzado el tamaño del buffer de picos se añade al buffer
        peakValues[peakCount] = emgBuffer[1]
        peakCount += 1

    if peakCount >= sampleSize: # Si se ha alcanzado el tamaño del buffer de picos, se calcula la media y la desviación estándar
        mean_peak = calcular_media(peakValues, peakCount)
        peakStdDev = calcular_std_dev(peakValues, peakCount, mean_peak)
        threshold = mean_peak + 9* peakStdDev #Se calcula el threshold como la media más 9 veces la desviación estándar

        calibrationDone = True

        print("Calibration complete")
        print(f" Mean peak: {mean_peak}")
        print(f" Std deviation: {peakStdDev}")
        print(f" Threshold (mean + 9σ): {threshold}")

        lastPeakValue = 0
        lowPeakCount = 0

def detectar_contraccion():
    # --- Función encargada de detectar si un pico es superior al threshold---
    global detected_peak

    if es_pico():
        current_peak = emgBuffer[1]

        if threshold <current_peak: # Si el pico actual es superior al threshold se determina que se ha detectado una contracción
            print(f"Pico bajo detectado: {current_peak}")
            print("🟢 Muscle ON detected")
            detected_peak = True

def es_pico():
    # --- Función encargada de detectar si es un pico durante la comprovación de la detección muscular---
    return emgBuffer[1] > emgBuffer[0] and emgBuffer[1] >emgBuffer[2] 

def es_pico_de_calibracion(value):
    # --- Función encargada de detectar si es un pico durante la calibración ---
    is_local_peak = emgBuffer[1]>emgBuffer[0] and emgBuffer[1] > emgBuffer[2]
    height_in_range = PEAK_MIN_HEIGHT <= emgBuffer[1] <= PEAK_MAX_HEIGHT
    return is_local_peak and height_in_range 

def calcular_media(values, size):
    # --- Función encargada de calcular la media ---
    return int(np.sum(values[:size]) / size)


def calcular_std_dev(values, size, mean):
    # --- Función encargada de calcular la desviación standard ---
    return int(np.sqrt(np.sum((values[:size] - mean) ** 2) / size))

def emg_deteccion(valor):
    # --- Función encargada de gestionar el proceso de calibración y detección de la contracción ---
    global emgData, calibrationStarted, calibrationStartTime, bufferFillCount
    if not calibrationStarted:
        calibrationStartTime = millis()
        calibrationStarted = True

    emgBuffer[0] = emgBuffer[1]
    emgBuffer[1] = emgBuffer[2]
    emgBuffer[2] = valor

    if bufferFillCount < 3:
        bufferFillCount += 1
        return

    if millis() - calibrationStartTime < 6000: # Si han pasado menos de 6 segundos desde el inicio de la función, se hace return sin hacer nada
        return

    if not peakRangeComputed:
        adquirir_picos_iniciales(emgData) # Si no se ha calculado el rango de picos, se adquieren los picos iniciales
        return

    if not calibrationDone:
        calibrar_threshold() # Si no se ha hecho la calibración, se calibra el threshold
        return

    detectar_contraccion() # Se detecta si hay contracción muscular

def polling_drdy():
    # --- Función principal de gestión de la lectura por EMG ---
    global chip, emgData, dataReady, live_filter, detected_peak
    while not detected_peak:
        if dataReady:
            dataReady=False
            # Flanco detectado
            leer_valores_ADS1292()
            emg_valor=emgData
            valor_filtrado =round(live_filter(emg_valor), 4)
            #print(valor_filtrado)
            emg_deteccion(valor_filtrado)
        time.sleep(0.00002)  # 200 us para no saturar CPU demasiado

class LiveSosFilter:
    # --- Clase que hace el filtro pasa bajos aplicado ---
    def __init__(self, sos):
        self.sos = np.atleast_2d(sos)
        self.n_sections = self.sos.shape[0]
        self.state = np.zeros((self.n_sections, 2))

    def __call__(self, x):
        """Apply SOS filter to a single sample."""
        for section in range(self.n_sections):
            b = self.sos[section, :3]
            a = self.sos[section, 3:]
            y = b[0] * x + self.state[section][0]
            self.state[section][0] = b[1] * x - a[1] * y + self.state[section][1]
            self.state[section][1] = b[2] * x - a[2] * y
            x = y
        return y
sos = scipy.signal.iirfilter(
    N=order,
    Wn=fc,
    fs=fs,
    btype='low',
    ftype='butter',
    output='sos'
)
live_filter = LiveSosFilter(sos)

# --- FUNCIONES REALIMENTACIÓN SERVOMOTORES ---

def servo_configuracion():
    # --- Función que configura los registros del ADS1292 para la lectura de la realimentación de los servomotores ---
    disable_continuous_reading()
    write_register(CONFIG1, config1Value)
    time.sleep(0.1)
    write_register(CONFIG2, config2Servo)
    time.sleep(0.1)
    write_register(CH1SET, ch1setServo)
    time.sleep(0.1)
    write_register(CH2SET, ch2setServo)
    time.sleep(0.1)
    write_register(RLD_SENS, rldsenseServo)
    time.sleep(0.1)
    write_register(RESP1, resp1Servo)
    time.sleep(0.1)
    write_register(RESP2, resp2Servo)

def servo_inicializacion():
    # --- Función encargada de la inicialización y correcta configuración del ADS1292 previa a la adquisición de datos de la retroalimentación de los servomotores ---
    global chip
    configuracion = False
    while not configuracion:
        reset_ads1292()
        servo_configuracion()
        configuracion=comprobar_registros("servo")   # Verifica registros
        time.sleep(0.008)     # delay(8) ms en Arduino
    start_conversion()
    time.sleep(0.01)

def servo_config():
    # --- Función principal encargada de gestionar las funciones para inicializar la configuración de la adquisición de datos de retroalimentación de los servomotores ---
    global chip, spi, dataReady
    activar_spi()
    servo_inicializacion()
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

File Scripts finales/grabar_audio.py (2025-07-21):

#!/usr/bin/env python3
import alsaaudio
import time
import wave
import os
import threading
import lgpio
import joblib
import unicodedata
from vosk import Model, KaldiRecognizer
from pydub import AudioSegment
import io
import json

# --- VARIABLES CONFIGURACIÓN I2S---
sampling_rate = 48000 # Frecuencia de muestreo
num_channels = 2 # Número de canales (2 para estéreo)
sample_width_bytes = 4  # 32 bits
MICRO_PIN = 26 # Pin GPIO para el micrófono

# --- VARIABLES ---
ruta_audio_base = "/home/raspberry/Grabacion" # Ruta base para guardar los audios grabados
#chip = None
etiqueta = " " # Etiqueta para almacenar la clasificación del audio
recording = False # Variable para indicar si se está grabando
recording_thread = None # Hilo para grabar audio
recorded_data = b'' # Datos grabados del audio
i2s_device = None # Dispositivo I2S
audio_grabado = False # Variable para indicar si ya se grabó un audio
datos_enviados_event = threading.Event() # Evento para indicar que ya se procesó un audio
modelo = None # Modelo de clasificación
vectorizador = None # Vectorizador TF-IDF
vosk_model = None # Modelo VOSK
modelos_cargados = False # Variable para indicar si los modelos están cargados
modelos_cargando = False # Variable para indicar si los modelos se están cargando
cola_audios_pendientes = [] # Lista para almacenar rutas de audios pendientes de procesar
cola_lock = threading.Lock() # Lock para manejar la cola de audios pendientes

# --- ALGORITMO CLASIFICADOR Y TRANSCRIPTOR VOSK ---
modelo_path = "/home/raspberry/vosk_models/modelo_vosk.pkl" 
vectorizador_path = "/home/raspberry/vosk_models/vectorizador_tfidf.pkl"
vosk_model_path = "/home/raspberry/vosk_models/vosk-model-small-es-0.42"


# --- FUNCIONES ---

def init_pin():
    # --- Función que configura el pin de grabación del audio  ---
    global chip
    lgpio.gpio_claim_input(chip, MICRO_PIN)

def compartir_chip(valor_chip):
    # --- Función que configura la variable chip con el valor Chip  ---
    global chip
    chip=valor_chip

def init_i2s():
    # --- Configura el I2S ---
    device = alsaaudio.PCM( # Dispositivo I2S utilizando ALSA
        type=alsaaudio.PCM_CAPTURE,
        mode=alsaaudio.PCM_NORMAL,
        device='hw:1,0'
    )
    # Configura el numero de canales, frecuencia de muestreo y formato
    device.setchannels(num_channels)
    device.setrate(sampling_rate)
    device.setformat(alsaaudio.PCM_FORMAT_S32_LE)
    device.setperiodsize(1024)
    return device

def loop_grabacion(device):
    # --- Función que graba el audio ---
    global recording, recorded_data
    frames = []
    print("Grabando...")
    while recording: # Mientras se esté grabando
        length, data = device.read()
        if length > 0:
            frames.append(data) # Añade los datos grabados a los frames
        else:
            time.sleep(0.01)
    recorded_data = b''.join(frames) # Une todos los frames grabados
    print("️ Grabación finalizada")

def guardar_wav(filename, audio_data):
    # --- Función que guarda el audio ---
    with wave.open(filename, 'wb') as wf:
        wf.setnchannels(num_channels)
        wf.setsampwidth(sample_width_bytes)
        wf.setframerate(sampling_rate)
        wf.writeframes(audio_data)

def cargar_modelos():
    # --- Función para cargar los modelos importados ---
    global modelo, vectorizador, vosk_model, modelos_cargados, modelos_cargando
    modelos_cargando = True
    print("Cargando modelos...")
    modelo = joblib.load(modelo_path) # Carga el modelo de clasificación
    vectorizador = joblib.load(vectorizador_path) # Carga el vectorizador TF-IDF
    vosk_model = Model(vosk_model_path) # Carga el modelo VOSK
    modelos_cargados = True
    modelos_cargando = False
    print("Modelos cargados.")
    threading.Thread(target=procesar_cola, daemon=True).start() # Cuando cargan los modelos, empezar a procesar cola

def convertir_audio(ruta_entrada):
    # --- Función que convierte el archivo WAV a mono de 16 KHz y 16 bits ---
    audio = AudioSegment.from_file(ruta_entrada)
    audio = audio.set_frame_rate(16000)
    audio = audio.set_sample_width(2)
    audio = audio.set_channels(1)
    buffer = io.BytesIO()
    audio.export(buffer, format="wav")
    buffer.seek(0)
    return buffer

def limpiar_texto(texto):
     # --- Función que limpia el texto convirtiendolo en minúsculas y eliminando acentos y caracteres especiales ---
    texto = texto.lower()
    texto = ''.join(
        c for c in unicodedata.normalize('NFD', texto) # Normaliza el texto
        if unicodedata.category(c) != 'Mn' # Elimina acentos
    )
    return texto

def transcribir_audio(ruta_audio):
     # --- Función que transcribe el audio con el transcriptor VOSK---
    global vosk_model
    wav_buffer = convertir_audio(ruta_audio)
    wf = wave.open(wav_buffer, "rb")
    rec = KaldiRecognizer(vosk_model, wf.getframerate()) # Crea el reconocedor VOSK
    rec.SetWords(True) # Configura el reconocedor para devolver palabras

    texto = ""
    while True:
        data = wf.readframes(4000) # Lee los datos del audio en bloques de 4000 frames
        if len(data) == 0:
            break
        if rec.AcceptWaveform(data): # Si el reconocedor acepta el bloque de audio
            result = json.loads(rec.Result()) # Obtiene el resultado
            texto += result.get("text", "") + " "
    final_result = json.loads(rec.FinalResult()) # Obtiene el resultado final
    texto += final_result.get("text", "") # Añade el texto final
    return texto.strip()

def clasificar_palabra(texto):
     # --- Función que vectoriza la transcripción y predice el agarre---
    global modelo, vectorizador
    texto_limpio = limpiar_texto(texto) # Limpia el texto
    X = vectorizador.transform([texto_limpio]) # Vectoriza el texto
    prediccion = modelo.predict(X) # Predice la clase del texto
    return prediccion[0]

def procesar_audio(ruta_audio):
    # --- Función principal encargada de la transcripción y clasificación del audio---
    global etiqueta
    print(f"Procesando audio: {ruta_audio}")
    transcripcion = transcribir_audio(ruta_audio) # Transcribe el audio
    etiqueta = clasificar_palabra(transcripcion) # Clasifica la transcripción
    print(f"Etiqueta: {etiqueta}")
    datos_enviados_event.set()  # Señalamos que ya procesamos un audio
    # No borramos el archivo para conservarlo
    try:
          os.remove(ruta_audio)
    except Exception as e:
           print(f"Error borrando archivo {ruta_audio}: {e}")

def procesar_cola():
    # --- Función encargada de guardar el audio en una cola y enviarlo a procesarlo---
    while True:
        cola_lock.acquire()
        if len(cola_audios_pendientes) == 0:
            cola_lock.release()
            time.sleep(1)  # Espera para no consumir CPU si está vacía
            continue
        audio_a_procesar = cola_audios_pendientes.pop(0) # Toma el primer audio de la cola
        cola_lock.release() # Libera el lock de la cola
        procesar_audio(audio_a_procesar) # Procesa el audio
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
